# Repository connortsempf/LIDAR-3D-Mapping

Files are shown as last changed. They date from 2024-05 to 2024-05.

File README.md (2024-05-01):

# LIDAR 3D Mapping
Final Project - Georgia Tech - Embedded Systems Design - ECE 4180 - Spring 2024<br>
Create 3D point models with the mBed microcontroller, basic hardware peripherals, and a 3D rendering desktop application
<br><br><br>

## Author
Connor Sempf - [connortsempf](https://github.com/connortsempf)
<br><br><br>

## Description
This project combines a bluetooth breakout board and two-servo, two-axis controlled LIDAR ToF scanner. It transmits polar coordinate data via USB virtual COM Port to a PC for mapping to 3D space coordinates in a pygame 3D rendering desktop application. This allows the user to visualize their scanned object and use the data for any 3D modelling application. Data is mapped and rendered in real-time so watching the LIDAR acquisition is possible. Manual servo control is enabled to calibrate a relative zero position for LIDAR alignment, and set new vertical and horizontal scanning range boundaries. 
<br><br><br>

## Features
- **LIDAR Distance Scanning**: The main component of this device setup is to retrieve distance scanning data from the LIDAR ToF sensor. The breakout board will return a millimeter distance value when called upon.
- **Bluetooth Control**: With the bluetooth chip, the user can communicate with the servos and LIDAR sensor to initialize a scanning period for rendering, set relative zero positions for the servos to create a repeatable starting point, and maneuver the actuators manually for determining a scanning range.
- **2-Axis Servo Maneuvering**: The user can instruct the servos to independently move vertically and horizontally by a variable degree interval. This gives an editable 2D area of scanning.
- **3D Rendering and Visualization**: The desktop python pygame application plots coordinate points in 3D space received from the mBED and LIDAR sensor to provide the user with a view of any scanned object. The software has full capability of rotating, scaling, and translating views to see the model from any angle.
- **3D Printed Supports**: Contained in this repository are 3D models and STL files for printing. These components are used to hold together the pivoting mechanism for the LIDAR sensor and servo motors.
<br><br><br>

## Devices and Components
**Hardware Components:**
- mBed LPC1768 Microcontroller - [Reference Site](https://os.mbed.com/platforms/mbed-LPC1768/)
- Adafruit Bluefruit LE Uart Bluetooth Board - [Reference Site](https://os.mbed.com/users/4180_1/notebook/adafruit-bluefruit-le-uart-friend---bluetooth-low-/)
- Adafruit VL53L0X LIDAR ToF Distance Sensor Board - [Reference Site](https://os.mbed.com/users/4180_1/code/HelloWorld_VL53L0X_LPC1768/)
- HiTEC HS-422 Deluxe Servo Motor (2) - [Reference Site](https://os.mbed.com/users/4180_1/notebook/an-introduction-to-servos/)<br><br>

**Miscellaneous Components:**
- 3D Printed Parts
- 30 Row Solderless Breadboard
- 63 Row Solderless Breadboard
- Mini-USB to USB-A Cable
- Smartphone with "Bluefruit Connect" App
- PC or Laptop
- 5V Supply
- Jumper Wires<br><br>

**Hardware Wiring Diagram:**<br><br>
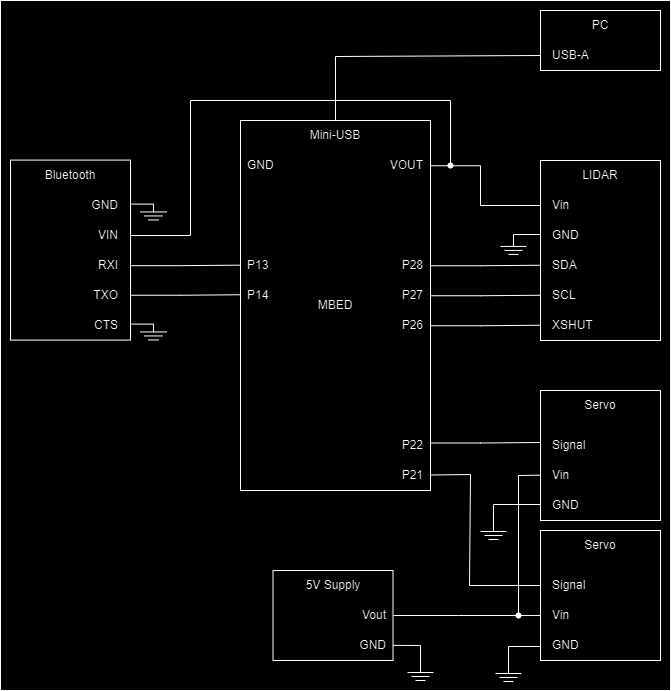
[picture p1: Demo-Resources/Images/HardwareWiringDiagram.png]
Hardware Wiring Diagram
<br><br>

**3D Printed Part Models:**<br><br>
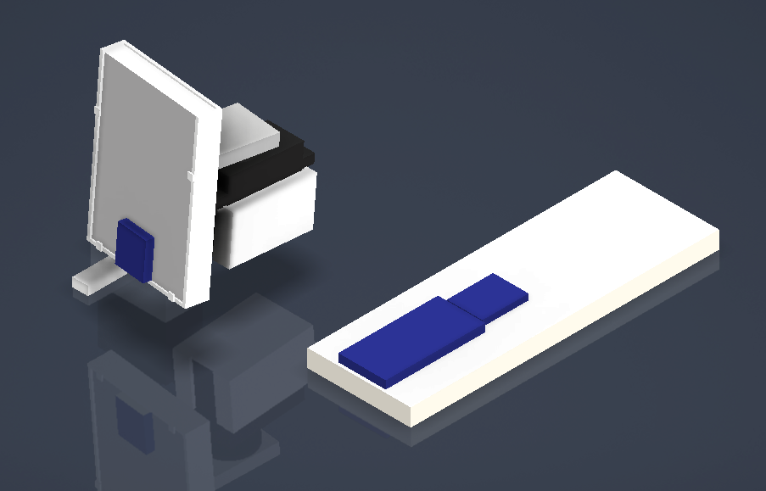
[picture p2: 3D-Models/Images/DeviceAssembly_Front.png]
Device Assembly Front

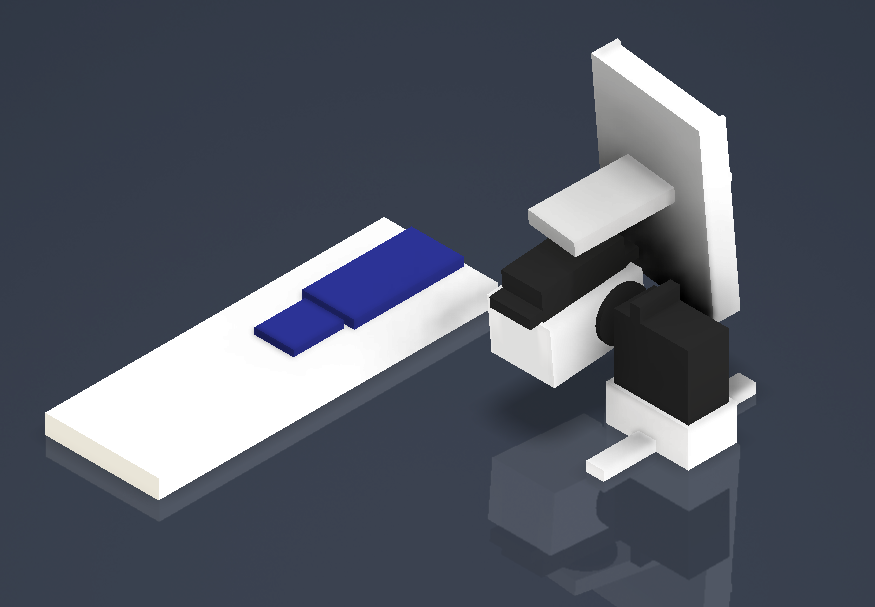
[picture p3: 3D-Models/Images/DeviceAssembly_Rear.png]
Device Assembly Rear
<br>
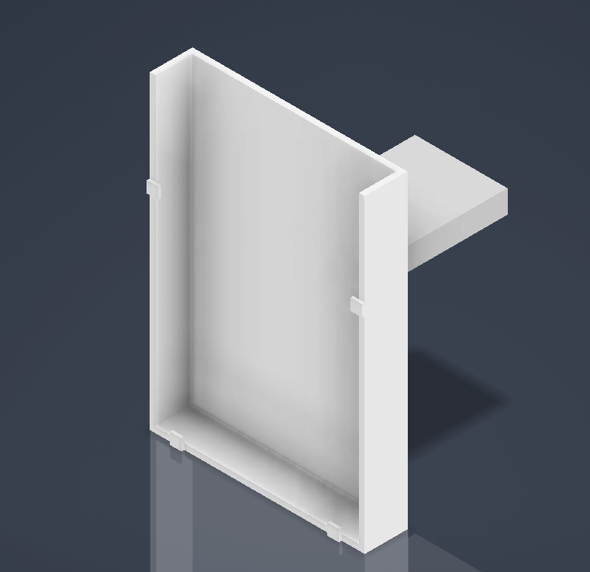
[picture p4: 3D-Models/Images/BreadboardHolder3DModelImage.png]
Breadboard Holder 3D Model Image

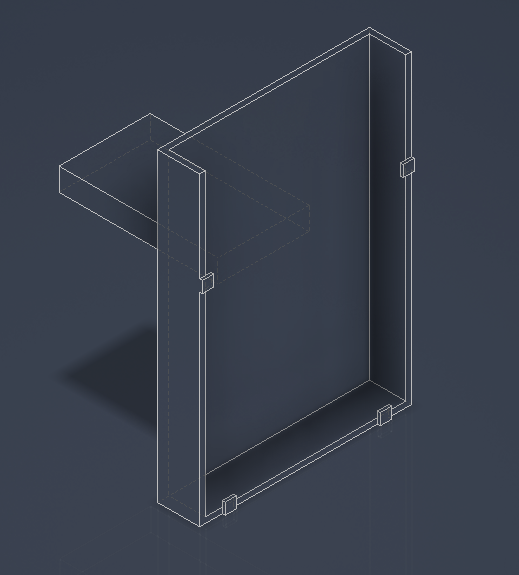
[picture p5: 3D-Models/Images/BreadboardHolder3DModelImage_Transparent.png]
Breadboard Holder 3D Model Image Transparent
<br>
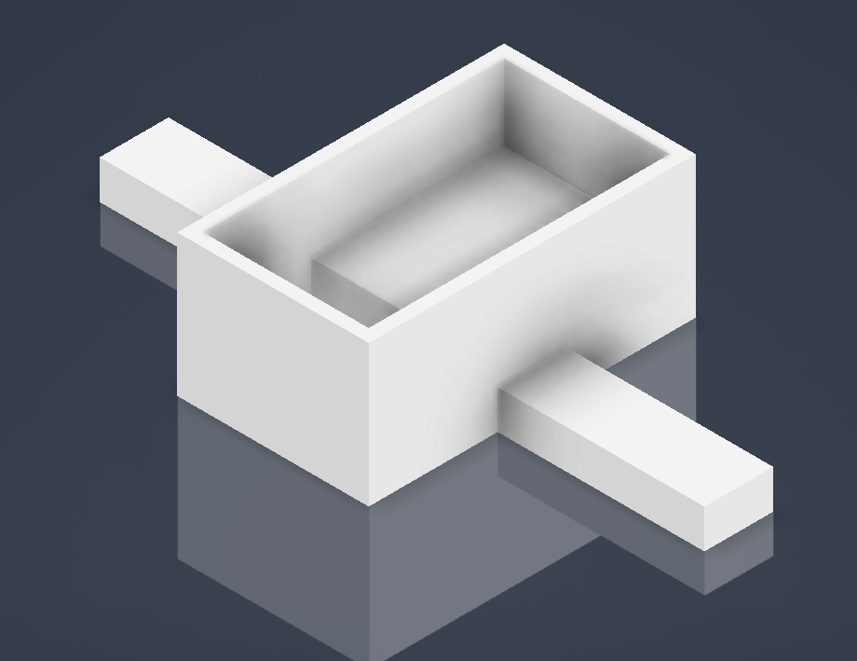
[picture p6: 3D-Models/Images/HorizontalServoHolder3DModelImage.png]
Horizontal Servo Holder 3D Model Image

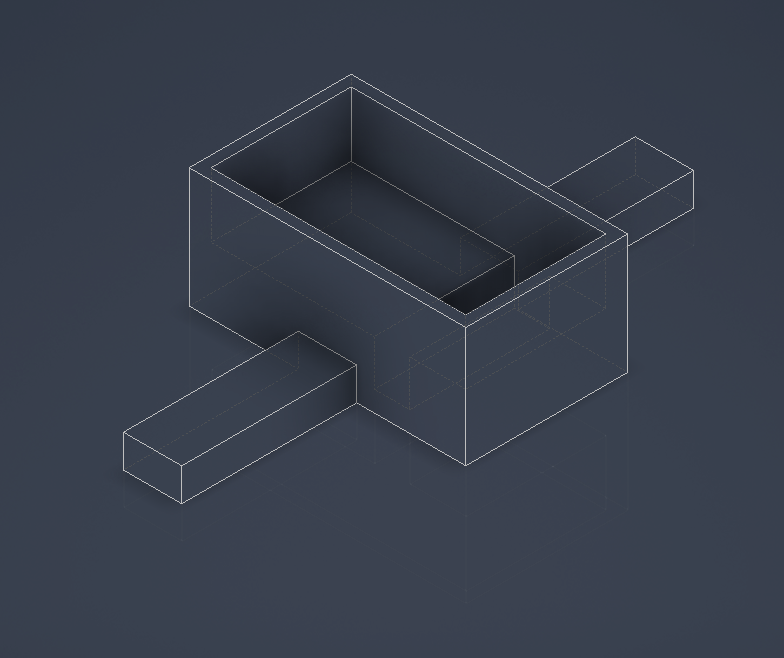
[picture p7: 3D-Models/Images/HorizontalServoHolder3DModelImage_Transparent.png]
Horizontal Servo Holder 3D Model Image Transparent
<br>
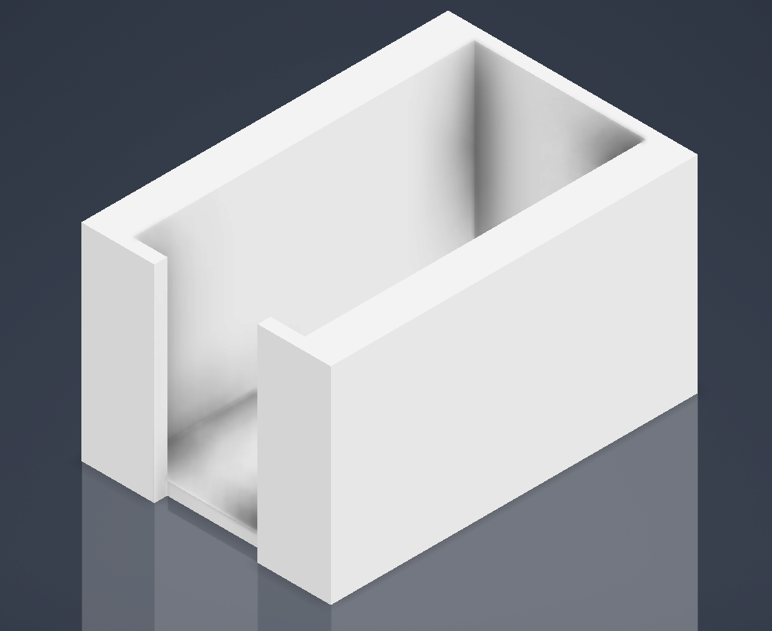
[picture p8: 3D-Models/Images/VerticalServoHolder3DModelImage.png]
Vertical Servo Holder 3D Model Image

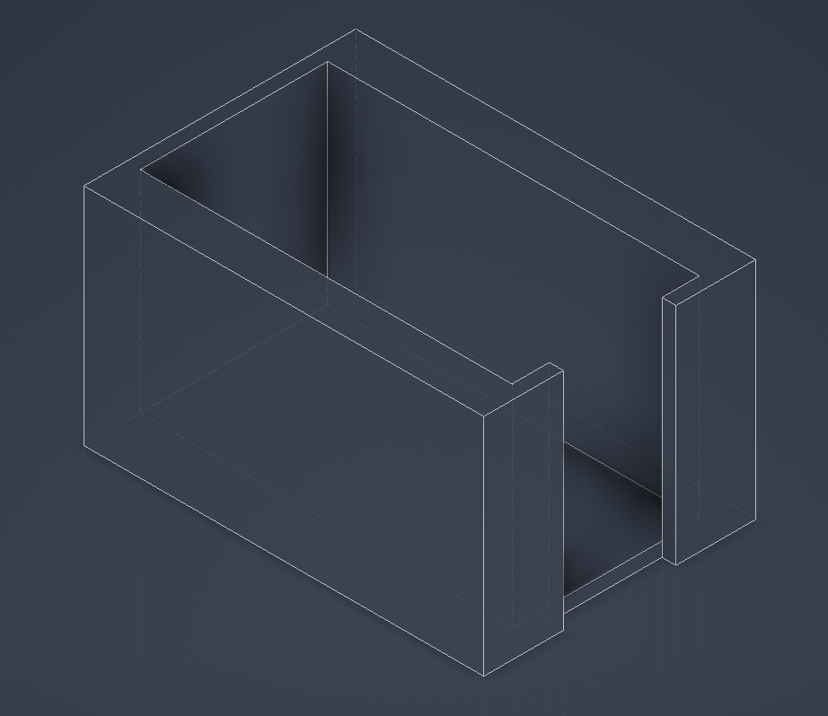
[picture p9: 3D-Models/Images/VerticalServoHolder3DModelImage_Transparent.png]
Vertical Servo Holder 3D Model Image Transparent

<br><br><br>

## Images and Demos
**Component Images:**<br><br>
Front View
Rear View<br>
Angled Rear View
Breadboard Top View<br>
Top View<br><br>
**Device Demos**:<br>
- [Servo Reset and Relative Zero Positioning](https://youtu.be/zzRhkBZBalc)
- [LIDAR Scanning Rear View](https://youtu.be/IgyYRwqueXU)
- [LIDAR Scanning Timelapse](https://youtu.be/QPMSIuET8sY)
- [Real Time Coordinate Mapping](https://youtu.be/MMdZRRT5r-Q)
- [Coordinate Rendering Visualization](https://youtu.be/nc9mq8p97Q0)<br><br>
<br><br><br>

## 3D Rendering Source Code
Files for the desktop application are found in the *LIDAR-Mapping-3D-Rendering-Source-Code* directory above.<br>
Make sure to run the *main.py* file and adjust the COM port if needed before starting the scanning sequence so the LIDAR data is actually mapped.
<br><br><br>

## Hardware Source Code
```c
#include "mbed.h"
#include "XNucleo53L0A1.h"
#include <cstdint>
#include <stdio.h>
#include "Servo.h"

// Servo //
#define absZeroPos              0.0
#define relativeZeroUDPos     -18.5
#define relativeZeroLRPos      -8.0
#define lidarMapUDStartPos    -10.0
#define lidarMapUDEndPos      -32.0
#define lidarMapLRStartPos    -20.0
#define lidarMapLREndPos        4.0
#define lidarPointsStep         1
#define variableRotate          0.5
#define autoRotate              0.25
Servo   udServo(p21);
Servo   lrServo(p22);
float   currentUDPos = 0;
float   currentLRPos = 0;
int     verticalLIDARPoints = (lidarMapUDStartPos - lidarMapUDEndPos) / lidarPointsStep;
int     horizontalLIDARPoints = (lidarMapLREndPos - lidarMapLRStartPos) / lidarPointsStep;

// LIDAR and I2C //
DigitalOut  shdn(p26);
#define     VL53L0_I2C_SDA   p28
#define     VL53L0_I2C_SCL   p27
static      XNucleo53L0A1 *board = NULL;
int         status;
uint32_t    lidarDistance;
uint32_t    lidarDistanceOffset = 34;
uint32_t    currentDistance;
DevI2C*     device_i2c = new DevI2C(VL53L0_I2C_SDA, VL53L0_I2C_SCL);

// Controller //
Serial controller(p13, p14);

// Serial Console //
Serial console(USBTX, USBRX);

// MBED LED's //
DigitalOut mbedLED1(LED1);
DigitalOut mbedLED2(LED2);
DigitalOut mbedLED3(LED3);
DigitalOut mbedLED4(LED4);

// Initialization Functions //
void initializeLIDARSensor() {
    board = XNucleo53L0A1::instance(device_i2c, A2, D8, D2);
    shdn = 0;
    wait(0.1);
    shdn = 1;
    wait(0.1);
    status = board->init_board();
    while (status) {
        console.printf("Failed to init board!\r\n");
        status = board->init_board();
    }
}

// General Functions //
void printServoPositions() {
    console.printf("Up/Down: %4.2f Left/Right: %4.2f\r\n", currentUDPos, currentLRPos);
}

void zeroPosUDServo() {
    if (currentUDPos > absZeroPos) {
        while (currentUDPos > absZeroPos) {
            currentUDPos = currentUDPos - autoRotate;
            udServo.position(currentUDPos);
            wait(0.01);
        }
    }   else if (currentUDPos < absZeroPos) {
        while (currentUDPos < absZeroPos) {
            currentUDPos = currentUDPos + autoRotate;
            udServo.position(currentUDPos);
            wait(0.01);
        }
    }
    currentUDPos = absZeroPos;
    udServo.position(absZeroPos);
}

void zeroPosLRServo() {
    if (currentLRPos > absZeroPos) {
        while (currentLRPos > absZeroPos) {
            currentLRPos = currentLRPos - autoRotate;
            lrServo.position(currentLRPos);
            wait(0.01);
        }
    }   else if (currentLRPos < absZeroPos) {
        while (currentLRPos < absZeroPos) {
            currentLRPos = currentLRPos + autoRotate;
            lrServo.position(currentLRPos);
            wait(0.01);
        }
    }
    currentLRPos = absZeroPos;
    lrServo.position(absZeroPos);
}

void zeroPosAllServos() {
    zeroPosUDServo();
    zeroPosLRServo();
    for (int i = 0; i < 4; i++) {
        mbedLED1 = !mbedLED1;
        mbedLED2 = !mbedLED2;
        mbedLED3 = !mbedLED3;
        mbedLED4 = !mbedLED4;
        wait(0.1);
    }
}

void relativeZeroPosUDServo() {
    if (currentUDPos > relativeZeroUDPos) {
        while (currentUDPos > relativeZeroUDPos) {
            currentUDPos = currentUDPos - autoRotate;
            udServo.position(currentUDPos);
            wait(0.01);
        }
    }   else if (currentUDPos < relativeZeroUDPos) {
        while (currentUDPos < relativeZeroUDPos) {
            currentUDPos = currentUDPos + autoRotate;
            udServo.position(currentUDPos);
            wait(0.01);
        }
    }
    currentUDPos = relativeZeroUDPos;
    udServo.position(relativeZeroUDPos);
}

void relativeZeroPosLRServo() {
    if (currentLRPos > relativeZeroLRPos) {
        while (currentLRPos > relativeZeroLRPos) {
            currentLRPos = currentLRPos - autoRotate;
            lrServo.position(currentLRPos);
            wait(0.01);
        }
    }   else if (currentLRPos < relativeZeroLRPos) {
        while (currentLRPos < relativeZeroLRPos) {
            currentLRPos = currentLRPos + autoRotate;
            lrServo.position(currentLRPos);
            wait(0.01);
        }
    }
    currentLRPos = relativeZeroLRPos;
    lrServo.position(relativeZeroLRPos);
}

void relativeZeroPosAllServos() {
    relativeZeroPosUDServo();
    relativeZeroPosLRServo();

    mbedLED1 = mbedLED2 = mbedLED3 = mbedLED4 = 0;
    for (int i = 0; i < 2; i++) {
        mbedLED1 = !mbedLED1;
        mbedLED2 = !mbedLED2;
        mbedLED3 = !mbedLED3;
        mbedLED4 = !mbedLED4;
        wait(0.1);
    }
}

void lidarMapStartingPosAllServos() {
    mbedLED1 = mbedLED2 = mbedLED3 = mbedLED4 = 0;
    for (int i = 0; i < 2; i++) {
        mbedLED1 = !mbedLED1;
        wait(0.1);
        mbedLED1 = !mbedLED1;
        mbedLED2 = !mbedLED2;
        wait(0.1);
        mbedLED2 = !mbedLED2;
        mbedLED3 = !mbedLED3;
        wait(0.1);
        mbedLED3 = !mbedLED3;
        mbedLED4 = !mbedLED4;
        wait(0.1);
        mbedLED4 = !mbedLED4;
    }

    while (currentUDPos < lidarMapUDStartPos) {
        currentUDPos = currentUDPos + autoRotate;
        udServo.position(currentUDPos);
        wait(0.01);
    }
    while (currentLRPos > lidarMapLRStartPos) {
        currentLRPos = currentLRPos - autoRotate;
        lrServo.position(currentLRPos);
        wait(0.01);
    }
    currentUDPos = lidarMapUDStartPos;
    udServo.position(currentUDPos);
    currentLRPos = lidarMapLRStartPos;
    lrServo.position(currentLRPos);
}

void rotateUpVariable(float rotationDegrees) {
    currentUDPos = currentUDPos + rotationDegrees;
    udServo.position(currentUDPos);
    printServoPositions();
}

void rotateDownVariable(float rotationDegrees) {
    currentUDPos = currentUDPos - rotationDegrees;
    udServo.position(currentUDPos);
    printServoPositions();
}

void rotateLeftVariable(float rotationDegrees) {
    currentLRPos = currentLRPos - rotationDegrees;
    lrServo.position(currentLRPos);
    printServoPositions();
}

void rotateRightVariable(float rotationDegrees) {
    currentLRPos = currentLRPos + rotationDegrees;
    lrServo.position(currentLRPos);
    printServoPositions();
}

uint32_t getLIDARDistance() {
    status = board->sensor_centre->get_distance(&lidarDistance);
    if (status == VL53L0X_ERROR_NONE) {
        return lidarDistance - lidarDistanceOffset;
    }
    return -1;
}

void reportDistance() {
    status = board->sensor_centre->get_distance(&lidarDistance);
    if (status == VL53L0X_ERROR_NONE) {
        currentDistance = getLIDARDistance();
        float LRPos = currentLRPos - relativeZeroLRPos;
        float UDPos = currentUDPos - relativeZeroUDPos;
        // X, Y, Z (distance) //
        console.printf("A %.2f\n", LRPos);
        console.printf("B %.2f\n", UDPos);
        console.printf("C %u\n", currentDistance);
    }
}

void mapLIDARPoints() {
    // Clear the Console for Easy Data Reading on 3D Rendering Side //
    console.printf("CLEAR\n");

    // Sweep Top to Bottom //
    for (int i = 0; i < verticalLIDARPoints; i = i + lidarPointsStep) {
        if (i % 2 == 0) {
            // Sweep Left to Right //
            for (int j = 0; j < horizontalLIDARPoints; j = j + lidarPointsStep) {
                currentLRPos = currentLRPos + lidarPointsStep;
                lrServo.position(currentLRPos);
                reportDistance();
            }
        }   else {
            // Sweep Right to Left //
            for (int j = 0; j < horizontalLIDARPoints; j = j + lidarPointsStep) {
                currentLRPos = currentLRPos - lidarPointsStep;
                lrServo.position(currentLRPos);
                reportDistance();
            }
        }
        currentUDPos = currentUDPos - lidarPointsStep;
        udServo.position(currentUDPos);
        reportDistance();
    }
}

int main() {

    // Initialization Processes //
    zeroPosAllServos();
    relativeZeroPosAllServos();
    initializeLIDARSensor();
    
    // Bluetooth Controller Variables //
    char controllerChar = 0;
    char controllerHit = 0;
    
    // Main Bluetooth Controller Thread //
    while (true) {
        if (controller.getc() == '!') {
            if (controller.getc() == 'B') {
                controllerChar = controller.getc();
                controllerHit = controller.getc();
                switch (controllerChar) {
                    // 1 Button //
                    case '1':
                        if (controllerHit == '1') {
                            relativeZeroPosAllServos();
                            lidarMapStartingPosAllServos();
                            mapLIDARPoints();
                        }
                        break;
                    // 3 Button //
                    case '3':
                        relativeZeroPosAllServos();
                        break;
                    // 4 Button //
                    case '4':
                        zeroPosAllServos();
                        break;
                    // Up Arrow Button //
                    case '5':
                        if (controllerHit == '1') {
                            rotateUpVariable(variableRotate);
                            mbedLED1 = 1;
                        }
                        break;
                    // Down Arrow Button //
                    case '6':
                        if (controllerHit == '1') {
                            rotateDownVariable(variableRotate);
                            mbedLED2 = 1;
                        }
                        break;
                    // Left Arrow Button //
                    case '7':
                        if (controllerHit == '1') {
                            rotateLeftVariable(variableRotate);
                            mbedLED3 = 1;
                        }
                        break;
                    // Right Arrow Button //
                    case '8':
                        if (controllerHit == '1') {
                            rotateRightVariable(variableRotate);
                            mbedLED4 = 1;
                        }
                        break;
                }
            }
        }
    }
}

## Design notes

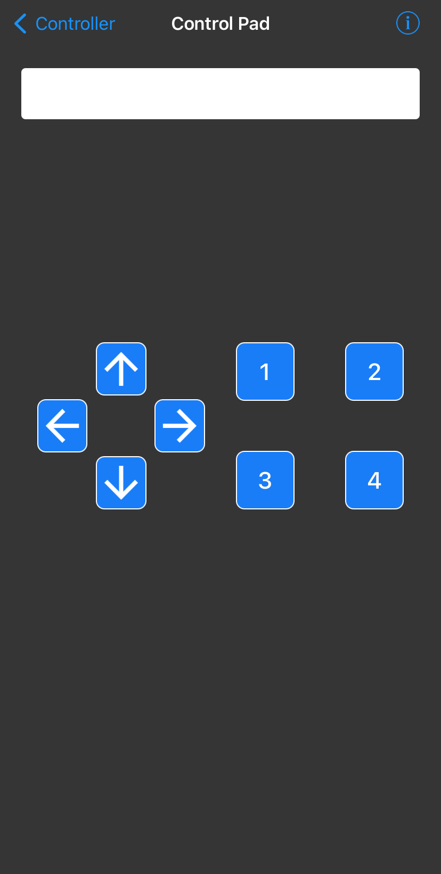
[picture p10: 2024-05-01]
Demo-Resources/Images/Bluetooth.png

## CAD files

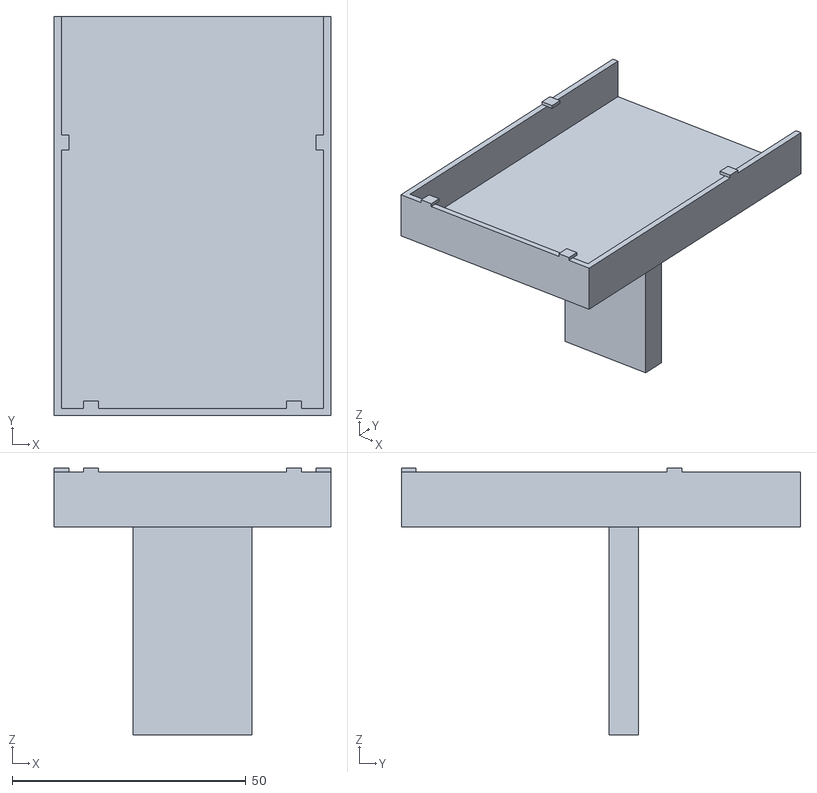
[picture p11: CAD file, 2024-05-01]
3D-Models/STLs/BreadboardHousing.stl
59.3 x 85.5 x 57.0

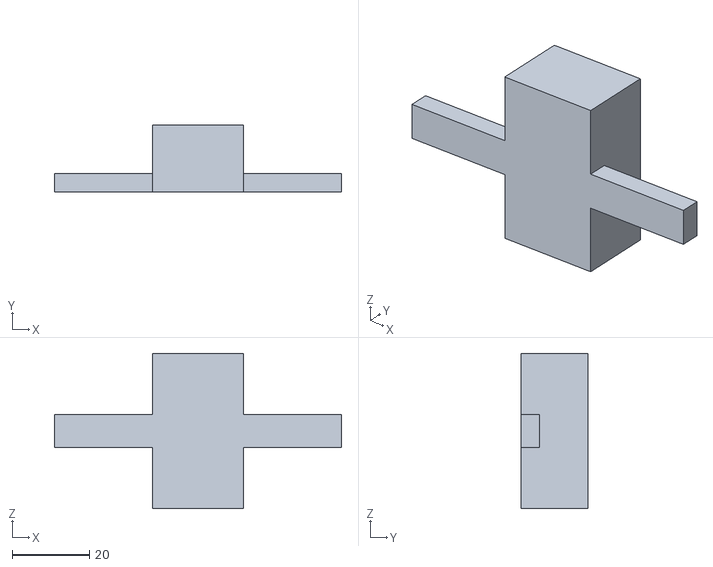
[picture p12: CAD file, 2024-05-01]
3D-Models/STLs/HorizontalRotationServoHolder.stl
74.3 x 17.4 x 40.2

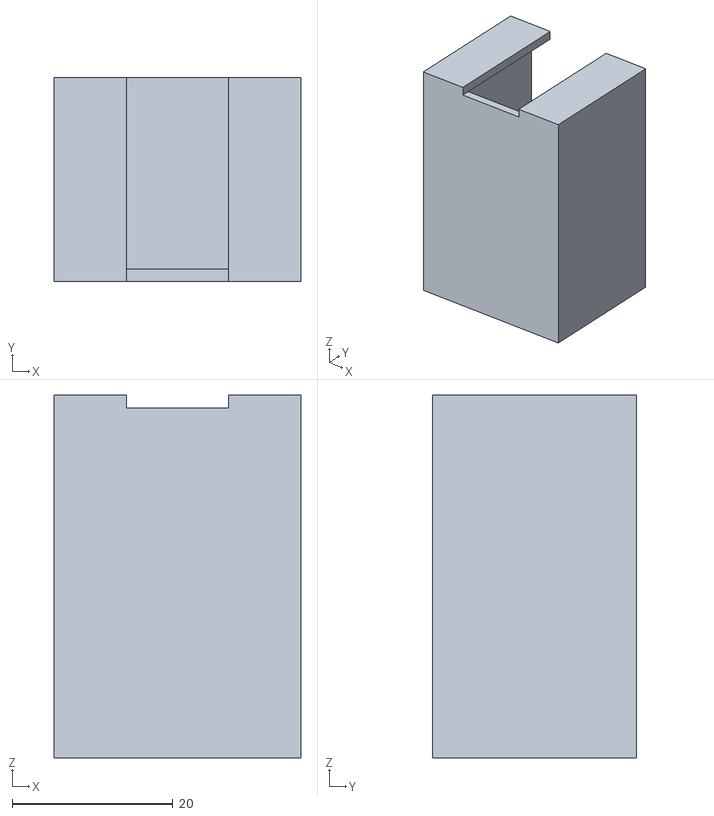
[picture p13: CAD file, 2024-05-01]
3D-Models/STLs/VerticalRotationServoHolder.stl
30.7 x 25.4 x 45.1

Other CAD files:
3D-Models/Assemblies/LIDAR-3D-Mapping.iam
3D-Models/Parts/3D Printed Parts/BreadboardHousing.ipt
3D-Models/Parts/3D Printed Parts/HorizontalRotationServoHolder.ipt
3D-Models/Parts/3D Printed Parts/VerticalRotationServoHolder.ipt
3D-Models/Parts/Project Components/30RowBreadboard.ipt
3D-Models/Parts/Project Components/63RowBreadboard.ipt
3D-Models/Parts/Project Components/Servo.ipt

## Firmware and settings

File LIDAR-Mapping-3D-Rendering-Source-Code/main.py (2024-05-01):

from pygame import init, quit, event, mouse, key, display, time, QUIT, VIDEORESIZE, KEYDOWN, MOUSEBUTTONUP, MOUSEBUTTONDOWN, K_ESCAPE, K_SPACE, MOUSEMOTION, MOUSEWHEEL
from random import randrange
import Window
import System
import Point
import LIDARSensor
import CoordinateReference
import DistanceExtraction

## Vertical and Horizontal Servo Arm to LIDAR Sensor Radius Offset: 1.8125" ##

WHITE  = "0xFFFFFF"
xRange = (-205, 205)
yRange = (-145, 145)
zRange = ( 392, 544)
lidarSensor = LIDARSensor.LIDARSensor()
window = Window.Window()
system = System.System()
coordinateReference = CoordinateReference.CoordinateReference()
distanceExtractor   = DistanceExtraction.DistanceExtraction()
points = []
distanceDataBuffer = []




def main():
    global distanceDataBuffer

    while system.running:
        system.clock.tick(system.fps)
        for pyEvent in event.get():
            if pyEvent.type == QUIT:
                distanceExtractor.closePort()
                system.quit()
            if pyEvent.type == KEYDOWN:
                if pyEvent.key == K_ESCAPE:
                    system.quit()
            ## Clear Points ##
            if pyEvent.type == KEYDOWN:
                if pyEvent.key == K_SPACE:
                    points.clear()
                    system.extractedDataCount = 0
            if pyEvent.type == MOUSEBUTTONDOWN:
                if pyEvent.button == 1:
                    system.mouseLeftDragging = True
                    system.mousePos = mouse.get_pos()
                elif pyEvent.button == 3:
                    system.mouseRightDragging = True
                    system.mousePos = mouse.get_pos()
            if pyEvent.type == MOUSEBUTTONUP:
                if pyEvent.button == 1:
                    system.mouseLeftDragging = False
                elif pyEvent.button == 3:
                    system.mouseRightDragging = False
            ## Zooming Transformations ##
            if pyEvent.type == MOUSEWHEEL:
                scrollAmount = pyEvent.y
                if scrollAmount > 0:
                    lidarSensor.zoomIn()
                    for point in points:
                        point.zoomIn()
                elif scrollAmount < 0:
                    lidarSensor.zoomOut()
                    for point in points:
                        point.zoomOut()
            if pyEvent.type == MOUSEMOTION:
                ## Rotating Transformations ##
                if system.mouseLeftDragging:
                    system.xRotation = system.mousePos[0] - pyEvent.pos[0]
                    system.yRotation = pyEvent.pos[1] - system.mousePos[1]
                    coordinateReference.rotateX(system.xRotation * system.xRotOffset)
                    coordinateReference.rotateY(system.yRotation * system.yRotOffset)
                    lidarSensor.rotateX(system.xRotation * system.xRotOffset)
                    lidarSensor.rotateY(system.yRotation * system.yRotOffset)
                    for point in points:
                        point.rotateX(system.xRotation * system.xRotOffset)
                        point.rotateY(system.yRotation * system.yRotOffset)
                    system.mousePos = pyEvent.pos
                ## Translating Transformations ##
                elif system.mouseRightDragging:
                    system.xTranslation = pyEvent.pos[0] - system.mousePos[0]
                    system.yTranslation = pyEvent.pos[1] - system.mousePos[1]
                    lidarSensor.translateX(system.xTranslation)
                    lidarSensor.translateY(system.yTranslation)
                    for point in points:
                        point.translateX(system.xTranslation)
                        point.translateY(system.yTranslation)
                    system.mousePos = pyEvent.pos

        ## mBed Coordinates Extraction ##
        distanceData = distanceExtractor.extractDistance()
        if distanceData:
            try:
                if distanceData[0] == "C":
                    distanceDataBuffer.append(int(distanceData[2:].strip()))
                    if distanceDataBuffer[2] != 0:
                        coordinates = distanceExtractor.getCoordinates(distanceDataBuffer[0], distanceDataBuffer[1], distanceDataBuffer[2])
                        points.append(Point.Point(coordinates[0], coordinates[1], coordinates[2], WHITE))
                        print(distanceDataBuffer)
                        distanceDataBuffer.clear()
                        system.extractedDataCount += 1
                    else:
                        print(distanceDataBuffer, "CLEARING")
                        distanceData.clear()
                elif distanceData[0] == "A" or distanceData[0] == "B":
                    distanceDataBuffer.append(float(distanceData[2:].strip()))
            except:
                pass

        ## Screen Rendering Drawing ##
        coordinateReference.draw(window)
        for point in points:
            point.draw(window)
        lidarSensor.drawPoints(window)
        lidarSensor.drawLIDARFOV(window)
        window.draw()

    quit()




if __name__ == "__main__":
    init()
    main()

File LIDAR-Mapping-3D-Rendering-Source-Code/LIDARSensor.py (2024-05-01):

from pygame import draw
from math import sin, cos, radians
import numpy as np


class LIDARSensor:

    originPointSize = 6
    pointSize = 3
    lineSize = 1
    zoomInCoefficient = 1.05
    zoomOutCoefficient = 0.95
    translationCoefficient = 5
    NAVY = "0xB3A369"
    GOLD = "0x003057"

    def __init__(self):
        self.origin = np.array([0.0, 0.0, 0.0])
        self.topLeft = np.array([-15.745752354, -11.19679625, 41.787012946])
        self.topRight = np.array([15.745752354, -11.19679625, 41.787012946])
        self.bottomLeft = np.array([-15.745752354, 11.19679625, 41.787012946])
        self.bottomRight = np.array([15.745752354, 11.19679625, 41.787012946])
        self.outerTopLeft = np.array([-186.400978110, -132.54963901, 544.681987300])
        self.outerTopRight = np.array([186.400978110, -132.54963901, 544.681987300])
        self.outerBottomLeft = np.array([-186.400978110, 132.54963901, 544.681987300])
        self.outerBottomRight = np.array([186.400978110, 132.54963901, 544.681987300])
    
    def drawPoints(self, window):
        draw.circle(window.window, LIDARSensor.NAVY, (self.topLeft[0] + (window.width // 2), self.topLeft[1] + (window.height // 2)), LIDARSensor.pointSize)
        draw.circle(window.window, LIDARSensor.NAVY, (self.topRight[0] + (window.width // 2), self.topRight[1] + (window.height // 2)), LIDARSensor.pointSize)
        draw.circle(window.window, LIDARSensor.NAVY, (self.bottomLeft[0] + (window.width // 2), self.bottomLeft[1] + (window.height // 2)), LIDARSensor.pointSize)
        draw.circle(window.window, LIDARSensor.NAVY, (self.bottomRight[0] + (window.width // 2), self.bottomRight[1] + (window.height // 2)), LIDARSensor.pointSize)
        draw.circle(window.window, LIDARSensor.GOLD, (self.origin[0] + (window.width // 2), self.origin[1] + (window.height // 2)), LIDARSensor.originPointSize)
    
    def drawLIDARFOV(self, window):
        draw.line(window.window, LIDARSensor.NAVY, (self.origin[0] + (window.width // 2), self.origin[1] + (window.height // 2)), (self.outerTopLeft[0] + (window.width // 2), self.outerTopLeft[1] + (window.height // 2)), LIDARSensor.lineSize)
        draw.line(window.window, LIDARSensor.NAVY, (self.origin[0] + (window.width // 2), self.origin[1] + (window.height // 2)), (self.outerTopRight[0] + (window.width // 2), self.outerTopRight[1] + (window.height // 2)), LIDARSensor.lineSize)
        draw.line(window.window, LIDARSensor.NAVY, (self.origin[0] + (window.width // 2), self.origin[1] + (window.height // 2)), (self.outerBottomLeft[0] + (window.width // 2), self.outerBottomLeft[1] + (window.height // 2)), LIDARSensor.lineSize)
        draw.line(window.window, LIDARSensor.NAVY, (self.origin[0] + (window.width // 2), self.origin[1] + (window.height // 2)), (self.outerBottomRight[0] + (window.width // 2), self.outerBottomRight[1] + (window.height // 2)), LIDARSensor.lineSize)

        draw.polygon(window.window, LIDARSensor.GOLD, [
                (self.origin[0] + (window.width // 2), self.origin[1] + (window.height // 2)),
                (self.bottomRight[0] + (window.width // 2), self.bottomRight[1] + (window.height // 2)),
                (self.bottomLeft[0] + (window.width // 2), self.bottomLeft[1] + (window.height // 2))
            ]
        )
        draw.polygon(window.window, LIDARSensor.NAVY, [
                (self.origin[0] + (window.width // 2), self.origin[1] + (window.height // 2)),
                (self.bottomLeft[0] + (window.width // 2), self.bottomLeft[1] + (window.height // 2)),
                (self.topLeft[0] + (window.width // 2), self.topLeft[1] + (window.height // 2))
            ]
        )
        draw.polygon(window.window, LIDARSensor.NAVY, [
                (self.origin[0] + (window.width // 2), self.origin[1] + (window.height // 2)),
                (self.topRight[0] + (window.width // 2), self.topRight[1] + (window.height // 2)),
                (self.bottomRight[0] + (window.width // 2), self.bottomRight[1] + (window.height // 2))
            ]
        )
        draw.polygon(window.window, LIDARSensor.GOLD, [
                (self.origin[0] + (window.width // 2), self.origin[1] + (window.height // 2)),
                (self.topLeft[0] + (window.width // 2), self.topLeft[1] + (window.height // 2)),
                (self.topRight[0] + (window.width // 2), self.topRight[1] + (window.height // 2))
            ]
        )

    def rotateX(self, angle = 0):
        xRotationMatrix = np.array([
            [cos(radians(angle)), 0, sin(radians(angle))],
            [0, 1, 0],
            [-sin(radians(angle)), 0, cos(radians(angle))]
        ])
        self.origin = xRotationMatrix @ self.origin
        self.topLeft = xRotationMatrix @ self.topLeft
        self.topRight = xRotationMatrix @ self.topRight
        self.bottomLeft = xRotationMatrix @ self.bottomLeft
        self.bottomRight = xRotationMatrix @ self.bottomRight
        self.outerTopLeft = xRotationMatrix @ self.outerTopLeft
        self.outerTopRight = xRotationMatrix @ self.outerTopRight
        self.outerBottomLeft = xRotationMatrix @ self.outerBottomLeft
        self.outerBottomRight = xRotationMatrix @ self.outerBottomRight
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

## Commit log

2024-05-01 Wiring Diagram Addition
2024-05-01 Data Dump
    [30RowBreadboard.ipt, 63RowBreadboard.ipt, BreadboardHousing.ipt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]
2024-05-01 Wiring Diagram Added
